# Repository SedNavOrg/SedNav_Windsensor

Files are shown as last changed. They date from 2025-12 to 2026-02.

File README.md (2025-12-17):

# SedNav_Windsensor

An open-source wind sensor design, taking inspiration from the project [Windsensor Yachta](https://github.com/norbert-walter/Windsensor_Yachta) by Norbert Walter.

It uses the same firmware, modified to work with this design.

The aims of this derivation are :

- To simplify the building process, by making the PCB easier to solder by hand

- To simplify the flashing, by using the ESP32C3 or C6 with a built-in USB interface (no more need for a serial to USB converter)

- To reduce the size of the wind sensor, by shrinking the pcb and reworking the design, in order to reduce the wind resistance, making it more resilient to winds.

- To test and validate the design in an actual wind tunnel.

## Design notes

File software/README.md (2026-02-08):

Pour faire un firmware merged pour l'ESP32C6, utiliser la commande : `pio run -t mergebin -e xiao_esp32c6`

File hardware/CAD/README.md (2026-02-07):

The CAD was done in OnShape.

Here is a link to the file, that you can copy or download : [https://centralelille.onshape.com/documents/f9b90260c58491739822fbe3/w/62acd9df5da8c8ddfe89f5b6/e/0e559c2feb2e8f1b7c776362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](https://centralelille.onshape.com/documents/f9b90260c58491739822fbe3/w/62acd9df5da8c8ddfe89f5b6/e/0e559c2feb2e8f1b7c776362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)

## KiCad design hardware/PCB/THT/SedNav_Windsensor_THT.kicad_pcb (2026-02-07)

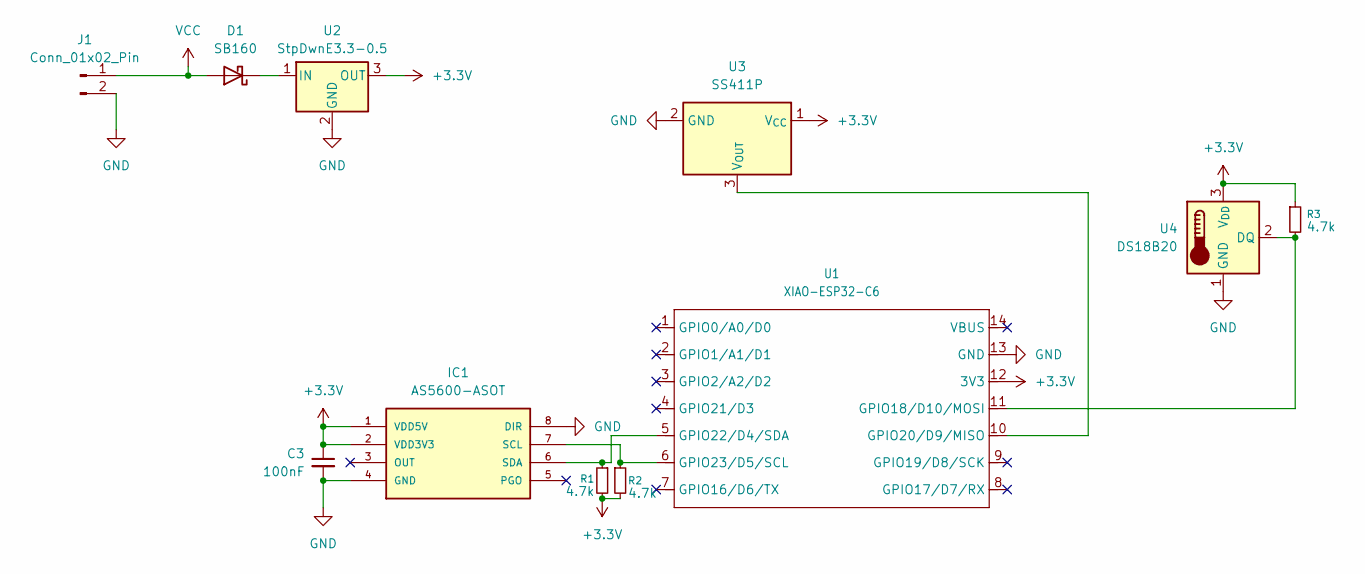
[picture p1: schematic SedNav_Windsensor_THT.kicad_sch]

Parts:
C3: 100nF; C_Disc_D4.7mm_W2.5mm_P5.00mm
D1: SB160; D_DO-41_SOD81_P7.62mm_Horizontal
IC1: AS5600-ASOT; SOIC127P600X175-8N; MOUSER_PART_NUMBER 985-AS5600-ASOT
J1: Conn_01x02_Pin; TerminalBlock_Phoenix_MPT-0,5-2-2.54_1x02_P2.54mm_Horizontal
R1, R2, R3: 4.7k; R_Axial_DIN0207_L6.3mm_D2.5mm_P7.62mm_Horizontal
U1: XIAO-ESP32-C6; XIAO-ESP32C6-THT
U2: StpDwnE3.3-0.5; CONV_R-78K3.3-0.5
U3: SS411P
U4: DS18B20; TO-92_Inline_Wide

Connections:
+3.3V: C3.1, IC1.1 (VDD5V), IC1.2 (VDD3V3), R1.2, R2.2, R3.1, U1.12 (3V3), U2.3 (OUT), U3.1 (V_{CC}), U4.3 (V_{DD})
GND: C3.2, IC1.4 (GND), IC1.8 (DIR), J1.2, U1.13 (GND), U2.2 (GND), U3.2 (GND), U4.1 (GND)
unnamed: D1.1 (K), U2.1 (IN)
unnamed: IC1.7 (SCL), R2.1, U1.6 (GPIO23/D5/SCL)
unnamed: IC1.6 (SDA), R1.1, U1.5 (GPIO22/D4/SDA)
unnamed: R3.2, U1.11 (GPIO18/D10/MOSI), U4.2 (DQ)
unnamed: U1.10 (GPIO20/D9/MISO), U3.3 (V_{OUT})
VCC: D1.2 (A), J1.1

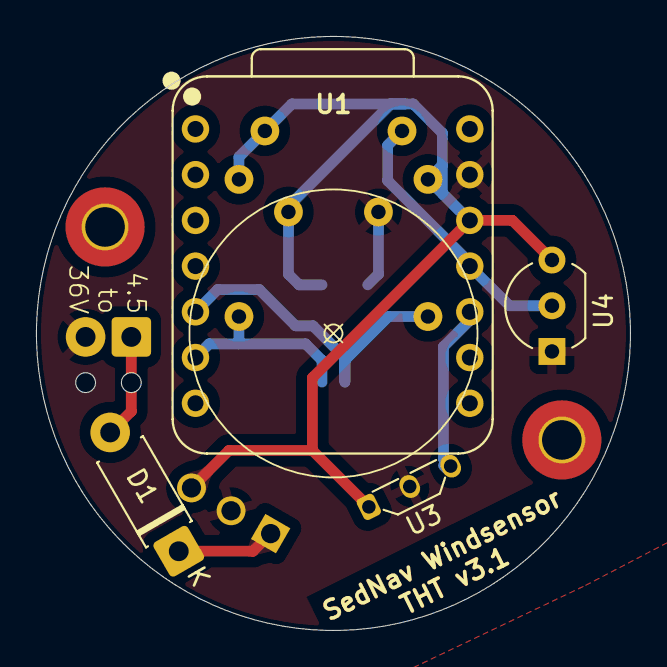
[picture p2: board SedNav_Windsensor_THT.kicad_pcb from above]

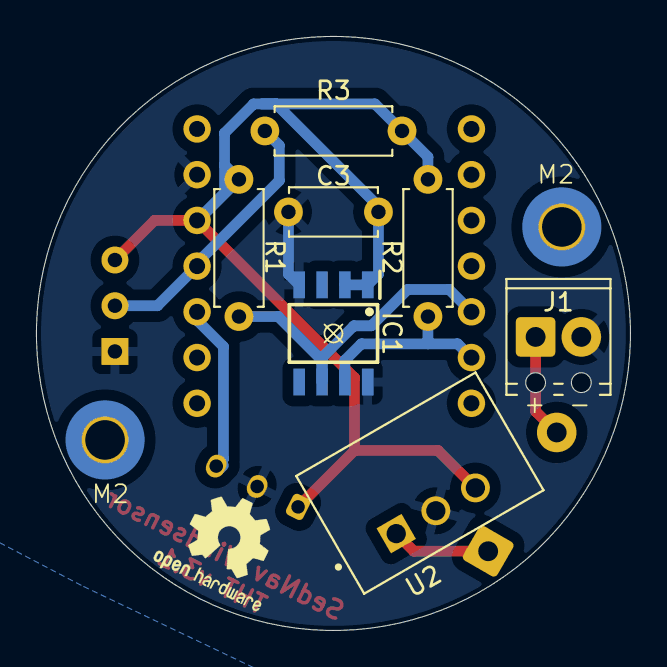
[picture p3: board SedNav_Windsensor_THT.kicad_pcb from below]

Board: 2 copper layers, 33.0 x 33.0 mm, 13 parts (9 on the bottom side), 8 nets.

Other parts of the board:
M2_1, M2_2: MountingHole_2.2mm_M2_Pad_TopBottom

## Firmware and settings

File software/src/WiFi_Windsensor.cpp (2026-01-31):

//*********************************************************************************************
// WiFi and NMEA server for transmitting wind sensor data via TCP connection
// (C) Norbert Walter 2023
// License: GNU GPL V3
// https://www.gnu.org/licenses/gpl-3.0.txt
//
// WiFi_Windsensor.cpp
//
// Tested and compiled with Visual Studio Code and PlatformIO
// Board esp8266 V2.7.4 (2.2.2-dev(38a443e))
// The server use different NMEA centeces
//
// Wind direction and speed:  $WIMWV,x.x,a,x.x,a,A*hh
// Wind direction and speed:  $WIVWR,x.x,a,x.x,N,x.x,M,x.x,K*hh
// Down wind speed:           $WIVPW,x.x,N,x.x,M*hh                               (Wind speed parallel to wind direction)
// Wind speed informations:   $PWINF,0,x.x,D,x.x,D,x.x,M,x.x,K,x.x,N,x.x,B,A*hh   (Custom sentence)
// Wind sensor temperature:   $PWWST,C,0,x.x,A*hh                                 (Custom sentence)
//
//*********************************************************************************************

// Includes
#include <WiFiClient.h>             // WiFi lib for clients

#ifdef ESP8266
  #include <ESP8266WiFi.h>    // WiFi lib with TCP server and client
  #include <ESP8266WebServer.h>       // WebServer lib
  #include <ESP8266mDNS.h>            // DNS lib
  #include <ESP8266HTTPUpdateServer.h>// Web Update server
  #include <OneWire.h>        // 1Wire network lib
#elif defined(ESP32)
  #include <WiFi.h>
  #include <WebServer.h>
  #include <ESPmDNS.h>
  #include <HTTPUpdateServer.h>
  #include "OneWireNg_CurrentPlatform.h"
#else
  #error "Unsupported platform"
#endif

#include <Ticker.h>         // Timer lib
#include <EEPROM.h>         // EEPROM lib
#include <WString.h>        // Needs for structures
#include <Wire.h>           // Lib for I2C
#include <Adafruit_Sensor.h>// Adafuit sensor lib
#include <Adafruit_BME280.h>// Lib for BME280
#include "AS5600.h"         // Lib for magnetic rotation sensor AS5600
#include "MT6701_I2C.h"     // Lib for magnetic rotation sensor MT6701
#include <DallasTemperature.h>// Dallas 1Wire lib
#include "Configuration.h"  // Setup data structure in header file
#include "Definitions.h"    // Local definitions in additional file

AMS_5600 ams5600;            // Declare magnetic rotation sensor AS5600
MT6701I2C mt6701(&Wire);    // Declare magnetic rotation sensor MT6701
Adafruit_BME280 bme;        // Declare environment sensor BME280
OneWire* oneWire = nullptr; // Declare 1Wire
DallasTemperature* DS18B20 = nullptr; // Declare DS18B20
configData actconf;         // Actual configuration, Global variable
                            // Overload with old EEPROM configuration by start. It is necessarry for port and serspeed
                            // Don't change the position!
size_t x = sizeof(long);
#include "Calculation.h"    // Function library for wind data calculation
#include "FunctionsLib.h"   // Function library
#include "NMEATelegrams.h"  // Function library for NMEA telegrams
#include "icon_html.h"      // Favorit icon
#include "css_html.h"       // CSS cascading style sheets
#include "steel_html.h"     // JavaScript steelseries_micro.js.gz library
#include "tween_html.h"     // JavaScript tween-min.js.gz library
#include "js_html.h"        // JavaScript functions
#include "main_html.h"      // Main webpage
#include "settings_html.h"  // Settings webpage
#include "firmware_html.h"  // Firmware update webpage
#include "json_html.h"      // JSON webpage
#include "json2_html.h"     // JSON webpage for Hall sensor signals
#include "MD5_html.h"       // JavaScript crypt password with MD5
#include "restart_html.h"   // Reset info webpage
#include "devinfo_html.h"   // Device info webpage
#include "windv_html.h"     // Wind value webpage
#include "windi_html.h"     // Wind instrument webpage
#include "error_html.h"     // Error 404 webpage

// Declarations
#if not defined(ESP32)
  int value;                  // Value from first byte in EEPROM
  bool empty;                  // If EEPROM empty without configutation then set to 1 otherwise 0
#endif
configData defconf;         // Definition of default configuration data
configData oldconf;         // Configuration stucture for old config data in EEPROM
configData newconf;         // Configuration stucture for new config data in EEPROM

#ifdef ESP8266
  ESP8266WebServer httpServer(actconf.httpport);  // Port for HTTP server
  ESP8266HTTPUpdateServer httpUpdater;            // Declaration update server
#elif defined(ESP32)
  WebServer httpServer(actconf.httpport);  // Port for HTTP server
  HTTPUpdateServer httpUpdater;            // Declaration update server
#else
  #error "Unsupported platform"
#endif
MDNSResponder mdns;                             // Activate DNS responder

#ifdef ESP32
  hw_timer_t *timer = NULL;
#endif
Ticker Timer2;              // Declare Timer2 for average building
Ticker Timer3;              // Declare Timer3 for normal NMEA data sending
Ticker Timer4;              // Declare Timer4 for reduced NMEA data sending
Ticker Timer5;              // Declare Timer5 for calculation of windspeed und winddirection 
WiFiServer server(actconf.dataport);  // Declare WiFi NMEA server port
 
//*********************************************************************************************
// Setup section
//*********************************************************************************************
void setup() {
  // setup flash on esp32
  #if defined(ESP32)
    esp_err_t err = nvs_flash_init();
    if (err == ESP_ERR_NVS_NO_FREE_PAGES || err == ESP_ERR_NVS_NEW_VERSION_FOUND) {
      DebugPrintln(3, "Error or new version of NVS_Flash found !");
      nvs_flash_erase();
      nvs_flash_init();
    }
  #endif

  // Make sure the antenna is correctly setup with the Xiao ESP32c6 board
  #if defined(ARDUINO_XIAO_ESP32C6)
    pinMode(WIFI_ENABLE, OUTPUT);
    digitalWrite(WIFI_ENABLE, LOW); // Power on the antenna switch
    delay(100);
    pinMode(WIFI_ANT_CONFIG, OUTPUT); // pinMode(14, OUTPUT);
    #if defined(USE_EXTERNAL_ANTENNA)
      digitalWrite(WIFI_ANT_CONFIG, HIGH); // HIGH = internal antenna (LOW by default)
    #else
      digitalWrite(WIFI_ANT_CONFIG, LOW); // LOW = internal antenna (LOW by default)
    #endif
  #endif
  // NOTE: First-boot EEPROM initialization is handled automatically below.
  // Uncomment the next line ONLY if you need to force reset EEPROM to defaults during development:
  // saveEEPROMConfig(defconf);  // Force initialize EEPROM with defaults

  #if not defined(ESP32)
    // Read the first byte from the EEPROM
    EEPROM.begin(sizeEEPROM);
    value = EEPROM.read(cfgStart);
    EEPROM.end(); 
    // If the fist Byte not identical to the first value in the default configuration then saving a default configuration in EEPROM.
    // Means if the EEPROM empty then saving a default configuration.
    if(value == defconf.valid){
      empty = false;                  // Marker for configuration is present
    }
    else{
      saveEEPROMConfig(defconf);
      empty = true;                  // Marker for configuration is missing
    }
  #endif
  // Loading EEPROM configuration
  actconf = loadEEPROMConfig(); // Overload with old EEPROM configuration by start. It is necessarry for serspeed

  // If the firmware version in EEPROM different to defconf then save the new version in EEPROM
  if(String(actconf.fversion) != String(defconf.fversion)){
    String fver = defconf.fversion;
    fver.toCharArray(actconf.fversion, 6);
    saveEEPROMConfig(actconf);
  }
 
  // Pin definitions and settings for wind sensor types
  switch (actconf.windSensorType)
  {
  case WIND_SENSOR_JUKOLEIN:
    // Pin redefinition for other wind sensor types (Original values see Definition.h)
    // Attention! GPIO 12 is not available! (1Wire)
    // Existing pins
    ledPin = 14;                // LED GPIO 14 (fake) (D5)
    INT_PIN1 = 2;               // Wind speed GPIO 2 (Hall sensor) (D4)
    INT_PIN2 = 16;              // Wind direction GPIO 16 (Hall sensor fake) (D0)
    // New pins
    I2C_SCL = 5;                // Wind direction magnetic sensor SCL GPIO 5 (AS5600) (D1)
    I2C_SDA = 4;                // Wind direction magnetic sensor SDA GPIO 4 (AS6500) (D2)
    break;

  case WIND_SENSOR_YACHTA:
    // Pin redefinition for other wind sensor types (Original values see Definition.h)
    // Attention! GPIO 12 is not available! (1Wire)
    // Existing pins
    ledPin = 2;                 // LED GPIO 2 (D4)
    INT_PIN1 = 14;              // Wind speed GPIO 14 (Reed switch) (D5), pin need 10k and 100n for spike reduction
    INT_PIN2 = 16;              // Wind direction GPIO 16 (Hall sensor fake) (D0)
    // New pins
    I2C_SCL = 5;                // Wind direction magnetic sensor SCL GPIO 5 (AS5600) (D1)
    I2C_SDA = 4;                // Wind direction magnetic sensor SDA GPIO 4 (AS6500) (D2)
    break;

  case WIND_SENSOR_YACHTA_2_0:
    // Pin redefinition for other wind sensor types (Original values see Definition.h)
    // Attention! GPIO 12 is not available! (1Wire)
    // Existing pins
    ledPin = 2;                 // LED GPIO 2 (D4)
    INT_PIN1 = 14;              // Wind speed GPIO 14 (Reed switch) (D5), pin need 10k and 100n for spike reduction
    INT_PIN2 = 16;              // Wind direction GPIO 16 (Hall sensor fake) (D0)
    // New pins
    I2C_SCL = 5;                // Wind direction magnetic sensor SCL GPIO 5 (MT6701) (D1)
    I2C_SDA = 4;                // Wind direction magnetic sensor SDA GPIO 4 (MT6701) (D2)
    mt6701.begin(I2C_SDA, I2C_SCL);
    break;

  case WIND_SENSOR_SEDNAV_C6:
    // Pin redefinition for other wind sensor types (Original values see Definition.h)
    oneWire_Bus = 18;
    // Existing pins
    ledPin = 15;                 // LED GPIO 2 (D4)
    INT_PIN1 = 20;              // Wind speed GPIO 14 (Reed switch) (D5), pin need 10k and 100n for spike reduction
    INT_PIN2 = -1;              // Wind direction unused
    // New pins
    I2C_SCL = 23;                // Wind direction magnetic sensor SCL GPIO 23 (AS5600) (D5)
    I2C_SDA = 22;                // Wind direction magnetic sensor SDA GPIO 22 (AS5600) (D4)
    break;

  case WIND_SENSOR_VENTUS:
    // Pin redefinition for other wind sensor types (Original values see Definition.h)
    // Attention! GPIO 12 is not available! (1Wire)
    // Existing pins
    ledPin = 2;                 // LED GPIO 2 (D4)
    INT_PIN1 = 14;              // Wind speed GPIO 14 (Reed switch) (D5), pin need 10k and 100n for spike reduction
    INT_PIN2 = 16;              // Wind direction GPIO 16 (Hall sensor fake) (D0)
    // New pins
    I2C_SCL = 5;                // Wind direction magnetic sensor SCL GPIO 5 (AS5600) (D1)
    I2C_SDA = 4;                // Wind direction magnetic sensor SDA GPIO 4 (AS6500) (D2)
    break;

  default:
    // WiFi 1000 - default configuration (already set in Definitions.h)
    break;
  }
  
  // Start OneWire
  oneWire = new OneWire(oneWire_Bus);
  DS18B20 = new DallasTemperature(oneWire);

  // Start bus systems
  Wire.begin(I2C_SDA, I2C_SCL);        // Start I2C
  bme.begin(i2cAddressBME280);         // Start BME280

  // Pin settings
  pinMode(INT_PIN1, INPUT_PULLUP);  // Interrupt input 1 speed
  if(INT_PIN2 >= 0)
  {
    pinMode(INT_PIN2, INPUT_PULLUP);  // Interrupt input 2 direction
  }
  pinMode(ledPin, OUTPUT);          // LED Pin output
  digitalWrite(ledPin, LOW);        // Switch LED on (inverted!)

  Serial.begin(actconf.serspeed);   // Start serial communication
  delay(10);

//  DebugPrint(3, "First EEPROM byte: ");
//  DebugPrintln(3, value);

  // Chip Information Data
  DebugPrintln(3, "Booting Sketch...");
  DebugPrint(3, actconf.devname);
  DebugPrint(3, " ");
  DebugPrint(3, windSensorTypeToString(actconf.windSensorType));
  DebugPrint(3, " ");
  DebugPrint(3, actconf.fversion);
  DebugPrintln(3, " (C) Norbert Walter");
  DebugPrintln(3, "*********************************************");
  DebugPrintln(3, "");

  #ifdef ESP8266
    DebugPrintln(3, "Module Type: ESP8266");
  #elif defined(ESP32)
    DebugPrintln(3, "Module Type: ESP32");
  #endif
  DebugPrint(3, "SDK-Version: ");
  DebugPrintln(3, ESP.getSdkVersion());
  DebugPrint(3, "Chip-ID: ");
  #ifdef ESP8266
    DebugPrintln(3, ESP.getChipId());
  #elif defined(ESP32)
    DebugPrintln(3, ESP.getChipModel());
  #endif
  DebugPrint(3, "Chip Speed [MHz]: ");  
  DebugPrintln(3, ESP.getCpuFreqMHz());
  DebugPrint(3, "Free Heap Size [Bytes]: ");
  DebugPrintln(3, ESP.getFreeHeap());
  DebugPrintln(3, "");
  DebugPrint(3, "Sensor ID: ");
  DebugPrintln(3, actconf.sensorID);
  DebugPrint(3, "Wind Sensor Type: ");
  DebugPrintln(3, windSensorTypeToString(actconf.windSensorType));
  DebugPrintln(3, "Sensor Type: Wind Speed");
  DebugPrint(3, "Input Pin: GPIO ");
  DebugPrintln(3, INT_PIN1);
  DebugPrintln(3, "Value Range [kn]: 0...73");
  DebugPrint(3, "Sensor Type: ");
  if(String(actconf.windType) == "R"){
      DebugPrintln(3, "Relative ");
    }
    else{
      DebugPrintln(3, "True ");
    }
  
  // Print wind direction sensor information
  switch (actconf.windSensorType)
  {
  case WIND_SENSOR_WIFI_1000:
    DebugPrintln(3, "Wind direction");
    DebugPrint(3, "Input Pin: GPIO ");
    DebugPrintln(3, INT_PIN2);
    DebugPrintln(3, "Value Range [°]: 0...360");
    break;

  case WIND_SENSOR_YACHTA:
  case WIND_SENSOR_JUKOLEIN:
  case WIND_SENSOR_VENTUS:
  case WIND_SENSOR_SEDNAV_C6:
    DebugPrintln(3, "Wind direction: AS5600");
    DebugPrint(3, "SCL: GPIO ");
    DebugPrintln(3, SCL);
    DebugPrint(3, "SDA: GPIO ");
    DebugPrintln(3, SDA);
    DebugPrint(3, "Scan I2C at address 0x");
    if (i2cAddressAS5600 < 0x10) {
      DebugPrint(3, "0");
    }
    DebugPrint(3, String(i2cAddressAS5600, HEX));
    DebugPrint(3, ": ");
    Wire.beginTransmission(i2cAddressAS5600);
    if(Wire.endTransmission() == 0){
      i2creadyAS5600 = true;                        // Result I2C scan
      DebugPrintln(3, "ready");
      DebugPrint(3, "Magnitude [1]: ");
      DebugPrintln(3, ams5600.getMagnitude());
      DebugPrint(3, "Raw Angle [°]: ");
      magsensor = ams5600.getRawAngle() * 0.087; // 0...4096 which is 0.087 of a degree
      DebugPrintln(3, magsensor);
    }
    else{
      i2creadyAS5600 = false;                        // Result I2C scan
      DebugPrintln(3, "error");
      DebugPrintln(3, "Stop I2C for device AS5600");
    }
    break;

  case WIND_SENSOR_YACHTA_2_0:
    DebugPrintln(3, "Wind direction: MT6701");
    DebugPrint(3, "SCL: GPIO ");
    DebugPrintln(3, SCL);
    DebugPrint(3, "SDA: GPIO ");
    DebugPrintln(3, SDA);
    DebugPrint(3, "Scan I2C at address 0x");
    if (i2cAddressMT6701 < 0x10) {
      DebugPrint(3, "0");
    }
    DebugPrint(3, String(i2cAddressMT6701, HEX));
    DebugPrint(3, ": ");
    Wire.beginTransmission(i2cAddressMT6701);
    if(Wire.endTransmission() == 0){
      i2creadyMT6701 = true;                       // Result I2C scan
      DebugPrintln(3, "ready");
      DebugPrint(3, "Raw Value: ");
      mt6701.begin();
      DebugPrintln(3, mt6701.getRawAngle());
      DebugPrint(3, "Raw Angle [°]: ");
      magsensor = mt6701.getDegreesAngle();     // 0...16384 which is 0.0219 of a degree
      DebugPrintln(3, magsensor);
    }
    else{
      i2creadyMT6701 = false;                       // Result I2C scan
      DebugPrintln(3, "error");
      DebugPrintln(3, "Stop I2C for device MT6701");
    }
    break;
  }

  if(actconf.windSensorType == WIND_SENSOR_VENTUS){
    DebugPrintln(3, "Environment Sensor: BME280");
    DebugPrint(3, "SCL: GPIO ");
    DebugPrintln(3, SCL);
    DebugPrint(3, "SDA: GPIO ");
    DebugPrintln(3, SDA);
    DebugPrint(3, "Scan I2C at address 0x");
    if (i2cAddressBME280 < 0x10) {
      DebugPrint(3, "0");
    }
    DebugPrint(3, String(i2cAddressBME280, HEX));
    DebugPrint(3, ": ");
    Wire.beginTransmission(i2cAddressBME280);
    if(Wire.endTransmission() == 0){
      i2creadyBME280 = true;                        // Result I2C scan
      DebugPrintln(3, "ready");
      DebugPrint(3, "Temperature [°C]: ");
      airtemperature = bme.readTemperature();
      DebugPrintln(3, airtemperature);      
      DebugPrint(3, "Air Pressure [mbar]: ");
      airpressure = bme.readPressure() / 100;
      DebugPrintln(3, airpressure);
      DebugPrint(3, "Air Humidity [%]: ");
      airhumidity = bme.readHumidity();
      DebugPrintln(3, airhumidity);
      DebugPrint(3, "Altitude [m]: ");
      altitude = bme.readAltitude(SEALEVELPRESSURE_HPA);
      DebugPrintln(3, altitude);
    }
    else{
      i2creadyBME280 = false;                        // Result I2C scan
      DebugPrintln(3, "error");
      DebugPrintln(3, "Stop I2C for device BME280");
    }
  }
    
  DebugPrintln(3, "Sensor Type: Sensor Temp 1Wire");
  DebugPrint(3, "Input Pin: GPIO ");
  DebugPrintln(3, oneWire_Bus);
  DebugPrintln(3, "Value Range [°C]: -55...125");
  DebugPrint(3, "Send Period [ms]: ");
  DebugPrintln(3, SendPeriod);
  DebugPrint(3, "Reduced Send Period [ms]: ");
  DebugPrintln(3, RedSendPeriod);
  DebugPrintln(3, "");
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
void loop() {
  
  httpServer.handleClient();        // HTTP Server-handler for HTTP update server
  #ifdef ESP8266
    MDNS.update();                    // Update DNS info
  #elif defined(ESP32)
    // Not needed, it is done automagically in the background
  #endif
  
  // Check if a client is connected
  WiFiClient client = server.accept();
  int i = 0;
  
  if(!client.connected() && WiFi.status() != WL_CONNECTED){
    digitalWrite(ledPin, LOW);      // LED on (Low activ)
    i = 0;
  }

  // While client is connected or Serial Mode is active
  while (client.connected() && !client.available()) {
    digitalWrite(ledPin, HIGH);     // LED off (Low activ)
    
    httpServer.handleClient();      // HTTP Server-handler for HTTP update server
    if(actconf.mDNS == 1){
      #ifdef ESP8266
        MDNS.update();                    // Update DNS info
      #elif defined(ESP32)
        // Note needed, it is done automagically in the background
      #endif
    }  
    
    if ((i == 0) && ((int(actconf.serverMode) == 0) || (int(actconf.serverMode) == 4))) {
      DebugPrintln(3, "Client connected");
      DebugPrintln(3, "");
    }

    // Wind speed and wind direction data calculated via Timer5 interrupt all 500ms

    // Sending NMEA data with normal speed
    if (windspeed_mps > 0 && flag1 == true){     
      i++;
      DebugPrintln(3, "");
      DebugPrint(3, "Send package:");
      DebugPrintln(3, i);
          
      if((int(actconf.serverMode) == 0) || (int(actconf.serverMode) == 1) || (int(actconf.serverMode) == 4)){
         if(int(actconf.windSensor) == 1){
          client.println(sendMWV(1));  // Send NMEA telegrams
          client.println(sendVWR(1));
          client.println(sendVPW(1));
          client.println(sendINF(1));
         }
        if(int(actconf.tempSensor) == 1){
          if(String(actconf.tempSensorType) == "DS18B20"){
            client.println(sendWST(1));
          }
          if(String(actconf.tempSensorType) == "BME280"){
            client.println(sendWSE(1));
          }    
        } 
      }
         
      flashLED(10);                 // Flash LED for data transmission
      flag1 = false;                // Reset the flag
    }

    // Sending NMEA data with reduced speed
    if (windspeed_mps <= 0 && flag2 == true){
      i++;
      DebugPrintln(3, "");
      DebugPrint(3, "Send package:");
      DebugPrintln(3, i);
      
      if((int(actconf.serverMode) == 0) || (int(actconf.serverMode) == 1) || (int(actconf.serverMode) == 4)){
        if(int(actconf.windSensor) == 1){
          client.println(sendMWV(1));  // Send NMEA telegrams
          client.println(sendVWR(1));
          client.println(sendVPW(1));
          client.println(sendINF(1));
        }
        if(int(actconf.tempSensor) == 1){
          if(String(actconf.tempSensorType) == "DS18B20"){
            client.println(sendWST(1));
          }
          if(String(actconf.tempSensorType) == "BME280"){
            client.println(sendWSE(1));
          }    
        }
      }
           
      flashLED(10);                 // Flash LED for data transmission
      flag2 = false;                // Reset the flag
    }

  }

  // If client not connected and server mode 1 (NMEA Serial) or server mode 4 (Demo)
  if(!client.connected() && (int(actconf.serverMode) == 1 || int(actconf.serverMode) == 4)){
    // Sending NMEA data with normal speed
    if (windspeed_mps > 0 && flag1 == true){  
      if(int(actconf.windSensor) == 1){
        sendMWV(1);  // Send NMEA telegrams
        sendVWR(1);
        sendVPW(1);
        sendINF(1);
      }
      if(int(actconf.tempSensor) == 1){
        if(String(actconf.tempSensorType) == "DS18B20"){
          sendWST(1);
        }
        if(String(actconf.tempSensorType) == "BME280"){
          sendWSE(1);
        }    
      }

      flashLED(10);                 // Flash LED for data transmission
      flag1 = false;                // Reset the flag
    }

    // Sending NMEA data with reduced speed
    if (windspeed_mps <= 0 && flag2 == true){      
      if(int(actconf.windSensor) == 1){
        sendMWV(1);  // Send NMEA telegrams
        sendVWR(1);
        sendVPW(1);
        sendINF(1);
      }
      if(int(actconf.tempSensor) == 1){
        if(String(actconf.tempSensorType) == "DS18B20"){
          sendWST(1);
        }
        if(String(actconf.tempSensorType) == "BME280"){
          sendWSE(1);
        }    
      }
           
      flashLED(10);                 // Flash LED for data transmission
      flag2 = false;                // Reset the flag
    }
  }

  delay(150);                       // Delay for load reducing
}

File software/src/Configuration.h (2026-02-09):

#ifndef Configuration_h
#define Configuration_h

// Default configuration
// Types 'byte' und 'word' doesn't work!

// Enum for wind sensor types
enum WindSensorType {
  WIND_SENSOR_WIFI_1000,
  WIND_SENSOR_YACHTA,
  WIND_SENSOR_YACHTA_2_0,
  WIND_SENSOR_JUKOLEIN,
  WIND_SENSOR_VENTUS,
  WIND_SENSOR_SEDNAV_C6
};

typedef struct {
  int valid = 11;                           // Number of configuration (Please change when the structure or values are changed)
  int crypt = 0;                            // Activate for critical webside a password query [0 = off|1 = on]
  char password[31] = "12345678";           // Password for critical websides (settings, update and reboot)
  char devname[21] = "Windsensor";          // Device name for web configuration
  char crights[16] = "SedNav (C) 2026";       // Copy rights
  char fversion[5] = "V3.1";               // Firmware version
  char license[10] = "GNU GPLv3";          // License type
  int debug = 3;                            // Debug mode 0=off 1=Errors 2=Errors + Warnings 3=Errors + Warnings + Messages
  char cssid[31] = "OpenPlotter";                // SSID of WiFi Client
  char cpassword[31] = "12345678";        // Password of WiFi Client
  int timeout = 30;                         // Connection timeout for client in [s] [30|90|120|150|180|210|240|270|300]
  char sssid[31] = "SedNav";                // SSID of WiFi Server
  char spassword[31] = "12345678";          // Password of WiFi Server
  int apchannel = 1;                        // Assess Point channel [1...13]
  int maxconnections = 2;                   // Max number of connection for WiFi clients [1...4]
  int mDNS = 1;                             // Using mDNS service [0|1] 0=off, 1=on
  char hostname [31] = "windsensor";        // Hostname WiFi Server
  int dataport = 6666;                      // Port for NMEA data output
  int httpport = 80;                        // Port for HTTP and update pages
  int serverMode = 0;                       // Used server mode [0|1|2|3|4] 0=HTTP (JSON, NMEA), 1=NMEA Serial, 2=MQTT, 3=Diagnostic, 4=Demo (Simulation data)
  int serspeed = 115200;                    // Serial speed in [Bd] 8N1 [300|1200|2400|4800|9600|19200|38400|57600|74880|115200]
  int skin = 0;                             // Skin for websides [0|1|2]
  char instrumentType[8] = "complex";       // Instrument type [simple|complex] simple = Canvas HTML5 , complex = Canvas Steel Series library
  int instrumentSize = 400;                 // Instrument size X * Y [pix] [200|250|300|350|400|450|500|550|600]
  int sensorID = 0;                         // ID of sensor [0...9]
  #ifndef SENSOR_TYPE
    #define SENSOR_TYPE WIND_SENSOR_WIFI_1000
  #endif
  WindSensorType windSensorType = SENSOR_TYPE;  // Type of wind sensor
  int windSensor = 1;                       // Send wind data 0=off 1=on (WIMWV, WIVWR, WIVPW, PWINF) or Serial or JSON
  char windType[2] = "R";                   // Type of wind R=relative, T=true
  int offset = 0;                           // Offset of wind direction [-180°...+180°]
  int average = 1;                          // Number of values for average building [1...10], for high speed use 1, default use 2
  char speedUnit[5] = "kn";                 // Unit of speed [m/s|km/h|kn|bft] for WIMWV
  int downWindSensor = 1;                   // Send data to down wind 0=off 1=on (WIVPW)
  int downWindRange = 50;                   // Down wind area = 180° +/- downWindRange
  #if (SENSOR_TYPE==WIND_SENSOR_SEDNAV_C6)
  float calslope = 0.762369444; // defaults for small sphericals
  float caloffset = 2.2435;
  #else
  float calslope = 1.0;                     // Speed sensor calibration slope, default 1.0
  float caloffset = 0.0;                    // Speed sensor calibration offset, default 0.0
  #endif
  char tempSensorType[10] = "DS18B20";      // Type of temperature sensor [Off|DS18B20|BME280]
  int tempSensor = 1;                       // Send data for temp 0=off 1=on (PWWST)
  char tempUnit[2] = "C";                   // Unit of temperature [C|F]
} configData;

#endif

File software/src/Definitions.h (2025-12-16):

#ifndef Definitions_h
#define Definitions_h           

// Passwort settings
String transactionID = String(random(0, 99999999));// Generate a random transaction ID by initialisation

// EEPROM settings (max size is 4096 Byte)
int cfgStart = 1024;              // Start adress in EEPROM (Attention! The first 32 Byte are used beginning with adress 0)
int sizeEEPROM = 2048;            // Used size of EEPROM 2kB (limit for config file size)

// WLAN client settings
String hname;                     // Hostname
int maxccounter;                  // Maximum number for connection tests until aborted (maxcounter = 60; 60 * 500ms = 30s waiting time)
int ccounter;                     // Actual connection test counter

// Settings for NMEA server 
int SendPeriod = 1000;            // SendPeriod in [ms], Attention! Range is limited [500...2000]
int RedSendPeriod = 3000;         // Reduced send period [ms] when wind speed is zero, range [2000...10000]
volatile bool flag1 = false;      // Flag for data sending (normal speed)
volatile bool flag2 = false;      // Flag for data sending (reduced speed)
volatile bool flag3 = false;      // Flag for zero wind speed detection (true = zero)

// Pin definitions WiFi 1000 wind sensor (default)
int ledPin = 2;                   // LED low activ GPIO 2 (D4)
int INT_PIN1 = 5;                 // Wind speed GPIO 5 (Hall sensor) (D1)
int INT_PIN2 = 4;                 // Wind direction GPIO 4 (Hall sensor) (D2)
int oneWire_Bus = 12;            // 1Wire bus on GPIO 12 (D6)

// I2C definitions
int I2C_SCL = 5;                  // I2C SCL
int I2C_SDA = 4;                  // I2C SDA
bool i2creadyAS5600 = false;           // Result of I2C scan for AS5600
byte i2cAddressAS5600 = 0x36;     // I2C address AS5600
bool i2creadyMT6701 = false;           // Result of I2C scan for MT6701
byte i2cAddressMT6701 = 0x06;     // I2C address MT6701
bool i2creadyBME280 = false;           // Result of I2C scan for BME280
byte i2cAddressBME280 = 0x76;     // I2C address BME280
#define SEALEVELPRESSURE_HPA (1013.25)// Sea level air pressure


// Measuring data (used in interrupt)
volatile int marker1 = 0;         // Wind speed
volatile int marker2 = 0;         // Wind direction
volatile int marker3 = 0;         // Marker for data saving in a array (sensor 1 and 2 binary switching data)
volatile int scounter = 0;        // Array counter for data saving (sensor1 and 2)
volatile int rpcounter = 0;       // Raw pulse counter for wind direction sensor (per revolution)
volatile int pcounter = 0;        // Pulse counter for wind direction sensor (per revolution)
volatile unsigned long icounter = 0;    // Interrupt counter for rotation detection
volatile unsigned long icounterold = 0; // Old interrupt counter for rotation detektion
volatile unsigned long counter1;  // Wind spped
volatile unsigned long counter2;  // Wind direction
volatile float time1;             // Wind speed (time in [ms] for one rotation)
volatile float time2;             // Wind direction (time in [ms] between wind speed sensor and wind direction sensor)
volatile int average;             // Number of values for average calculation [1...10]
volatile float timearray1[10];    // Array1 of time values (average building)
volatile float timearray2[10];    // Array2 of time values (average building)
volatile int mc = 0;              // Modulo counter
volatile float time1_avg;         // Average wind speed (time in [ms] for one rotation)
volatile float time2_avg;         // Average direction (time in [ms] between wind speed sensor and wind direction sensor)

static float radius = 0.06;       // Radius between center and middle of half hemisphere position (WiFi 1000)
static float radius2 = 0.043;     // Radius between center and middle of half hemisphere position (Yachta|Jukolein)
static float radius3 = 0.055;     // Radius between center and middle of half hemisphere position (Ventus)
static float lamda = 0.3;         // Lambda is a constant for amemometer type with 3 hemisphere, lamda = 0,3
static constexpr float pi = 3.14159265358979;   // Pi constant
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

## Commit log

2025-10-15 Corrected component sizes and added teardrops
    [OpenNav_Windsensor.kicad_pcb, OpenNav_Windsensor.kicad_sch]
2025-11-04 Modified PCB to match Simon's remarks Moved the esp32 to a side, to be able to access the usb port Simplified the routing Made the board more aesthetically pleasing
    [OpenNav_Windsensor.kicad_pcb]
2025-11-15 Added software, corrected for ESP32C6 (untested)
    [Configuration.h, OpenNav_Windsensor.kicad_pcb, OpenNav_Windsensor.kicad_sch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]
2025-11-25 Firmware partialy operational. Need to correct the temperature, and verify the NMEA works.
    [Configuration.h]
2025-12-15 Corrected EEPROM initialization and saving function. Verified connecting to boat wifi works.
    [WiFi_Windsensor.cpp]
2025-12-16 Corrected temperature sensor bug
    [OpenNav_Windsensor.kicad_sch]
2025-12-19 Correction de la connexion avec hotspot non sécurisé
    [WiFi_Windsensor.cpp]
2025-12-21 v2 du PCB (en THT)
    [OpenNav_Windsensor.kicad_pcb, OpenNav_Windsensor.kicad_sch, OpenNav_Windsensor.step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]
2026-01-22 Changed connector
    [SedNav_Windsensor_THT.kicad_pcb, SedNav_Windsensor_THT.kicad_sch]
2026-01-22 Version alpha d'une version SMD de la carte élec
    [SedNav_Windsensor_SMD.kicad_pcb, SedNav_Windsensor_SMD.kicad_sch]
2026-01-31 V3.1 du PCB THT
    [SedNav_Windsensor_THT.kicad_pcb, SedNav_Windsensor_THT.kicad_sch]
2026-01-31 Mise un jour d'un pin du firmware, et suppression du c3
2026-02-07 Version finale, fin du projet
    [SedNav_Windsensor_THT.kicad_pcb]
2026-02-07 Ajout du lien vers la CAO OnShape
2026-02-07 Ajout des licences
2026-02-08 Ajout de la possibilité de faire un firmware merged
2026-02-09 Corrected wind speed readings when no wind is present
    [Calculation.h]
2026-02-09 Mise à jour des valeurs par défaut pour le windsensor sednav
    [Configuration.h]
